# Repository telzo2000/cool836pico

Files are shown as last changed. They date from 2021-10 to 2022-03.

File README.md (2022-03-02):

# cool836pico

# build guide
https://github.com/telzo2000/cool836pico/blob/main/buildguide_cool836pico.md

# Note
cool836picoを完成したので、忘備録として記入します。
<br>
cool836picoは、m.kiが設計したキーボードです。<br>
cool836Aをベースにして、従来のpro microから、Raspberry pi pico（以下、ピコ）を採用し、配線処理等を新規設計したものである。<br>
特徴は、前述のピコを採用したこと。<br>
cool836Aと同じ、アリス配列をもしたキーレイアウトであること。<br>
スイッチソケットを採用して、Cherry MXとkailh chocの両方が使えること。<br>
これら３点が挙げられる。<br>
基板の設計は、kicadで行った。すでにピコのfootprintを作った人がいたので、それを使った。
キーレイアウトは、cool836Aと同じため、前に使ったレイアウトのjsonファイルを再利用した。
配線処理は、cool836Aが最初にSU120を使ったものであったときの名残りで、colとrowは６x６であった。
この点を改善しようと思い、１２x３に変更した。その分、配線処理は簡易となったと思う。<br>
ピコはpro microと違い、基板本体にリセットスイッチを持っている。そのため、基板への設置面に制約がある。
なるべく、チップ類が露出しない方が良いと考えて、PCBに切り込みを入れる形にした。
マックエイトのスプリングピンヘッダを使用する限り、あまり関係ない仕様かもしれない。
一般的なピンヘッダでハンダ付けをした場合、この仕様は生きてくると思う。<br>
ネジ穴の位置は、外装となるアクリルプレートを考慮して配置した。
ただし、二種類の高低差のあるスイッチが使用できるため、それに合わせたスイッチプレートの形状とした。
結果として、ピコのカバー部分のアクリルプレートを２種類用意することで解決した。<br>
これまでのcool836Aのような形状では難しくなり、菱形のような形状となった。
今後、ピコの設置の場所について、洗練できれば、形状の見直しも視野に入れようと思う。<br>
ファームウェアについては、python系のkmk_firmwarexとrubyのprk_firmwareの２種類がある。両方試してみた。
どちらにもいえることが、pro microで使うqmk_firmwareよりも多分、作りやすいと思う。
逆にどちらもコンパイルの場面がないので、エラー表示を見て一つ一つ直していくことができない。
原因を探るのが難しかった。<br>
最初に上手く行ったのは、prk_firmwareのほうだった。
しかし、この文章はkmk_firmwareを装備したcool836picoで入力している。<br>
~~今後、どちらが優位になるか、私にはわからない。~~<br>
（令和4年２月25日追記）<br>
最近、メンテナンスに時間を割くことができず、記述が古いままでした。
ちょっとだけ時間に余裕ができたので、追記します。
<br>
cool836picoは、よくわかりませんが、prk_firmwareでも、kmk_firmawareでも動作します。
<br>
cool836rpの初期版（boothで＜訳あり版＞として頒布）は、prkでファームが作れたのですが、なぜか、kmkで作れませんでした。
GP29を使用したのが、ダメだったのかと勝手に考えています。
<br>そのため、cool836rp＜正式版＞では、GP29を使わないで配線してあります。
<br>
私自身、何度も書きますが、非IT系の業界で、この辺りの知識量はとても少なく、先人たちの足跡を追いながら、日々精進している状態です。

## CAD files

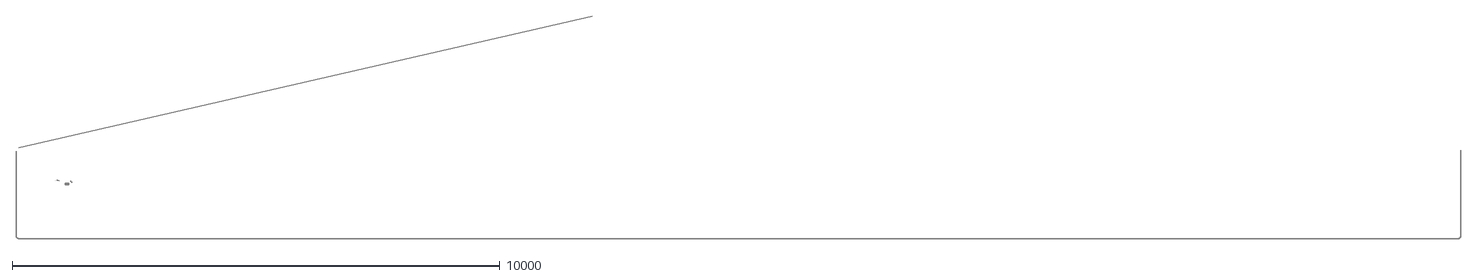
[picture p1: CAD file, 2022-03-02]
case/cool836picocasedesig.dxf
29627.7 x 4564.4

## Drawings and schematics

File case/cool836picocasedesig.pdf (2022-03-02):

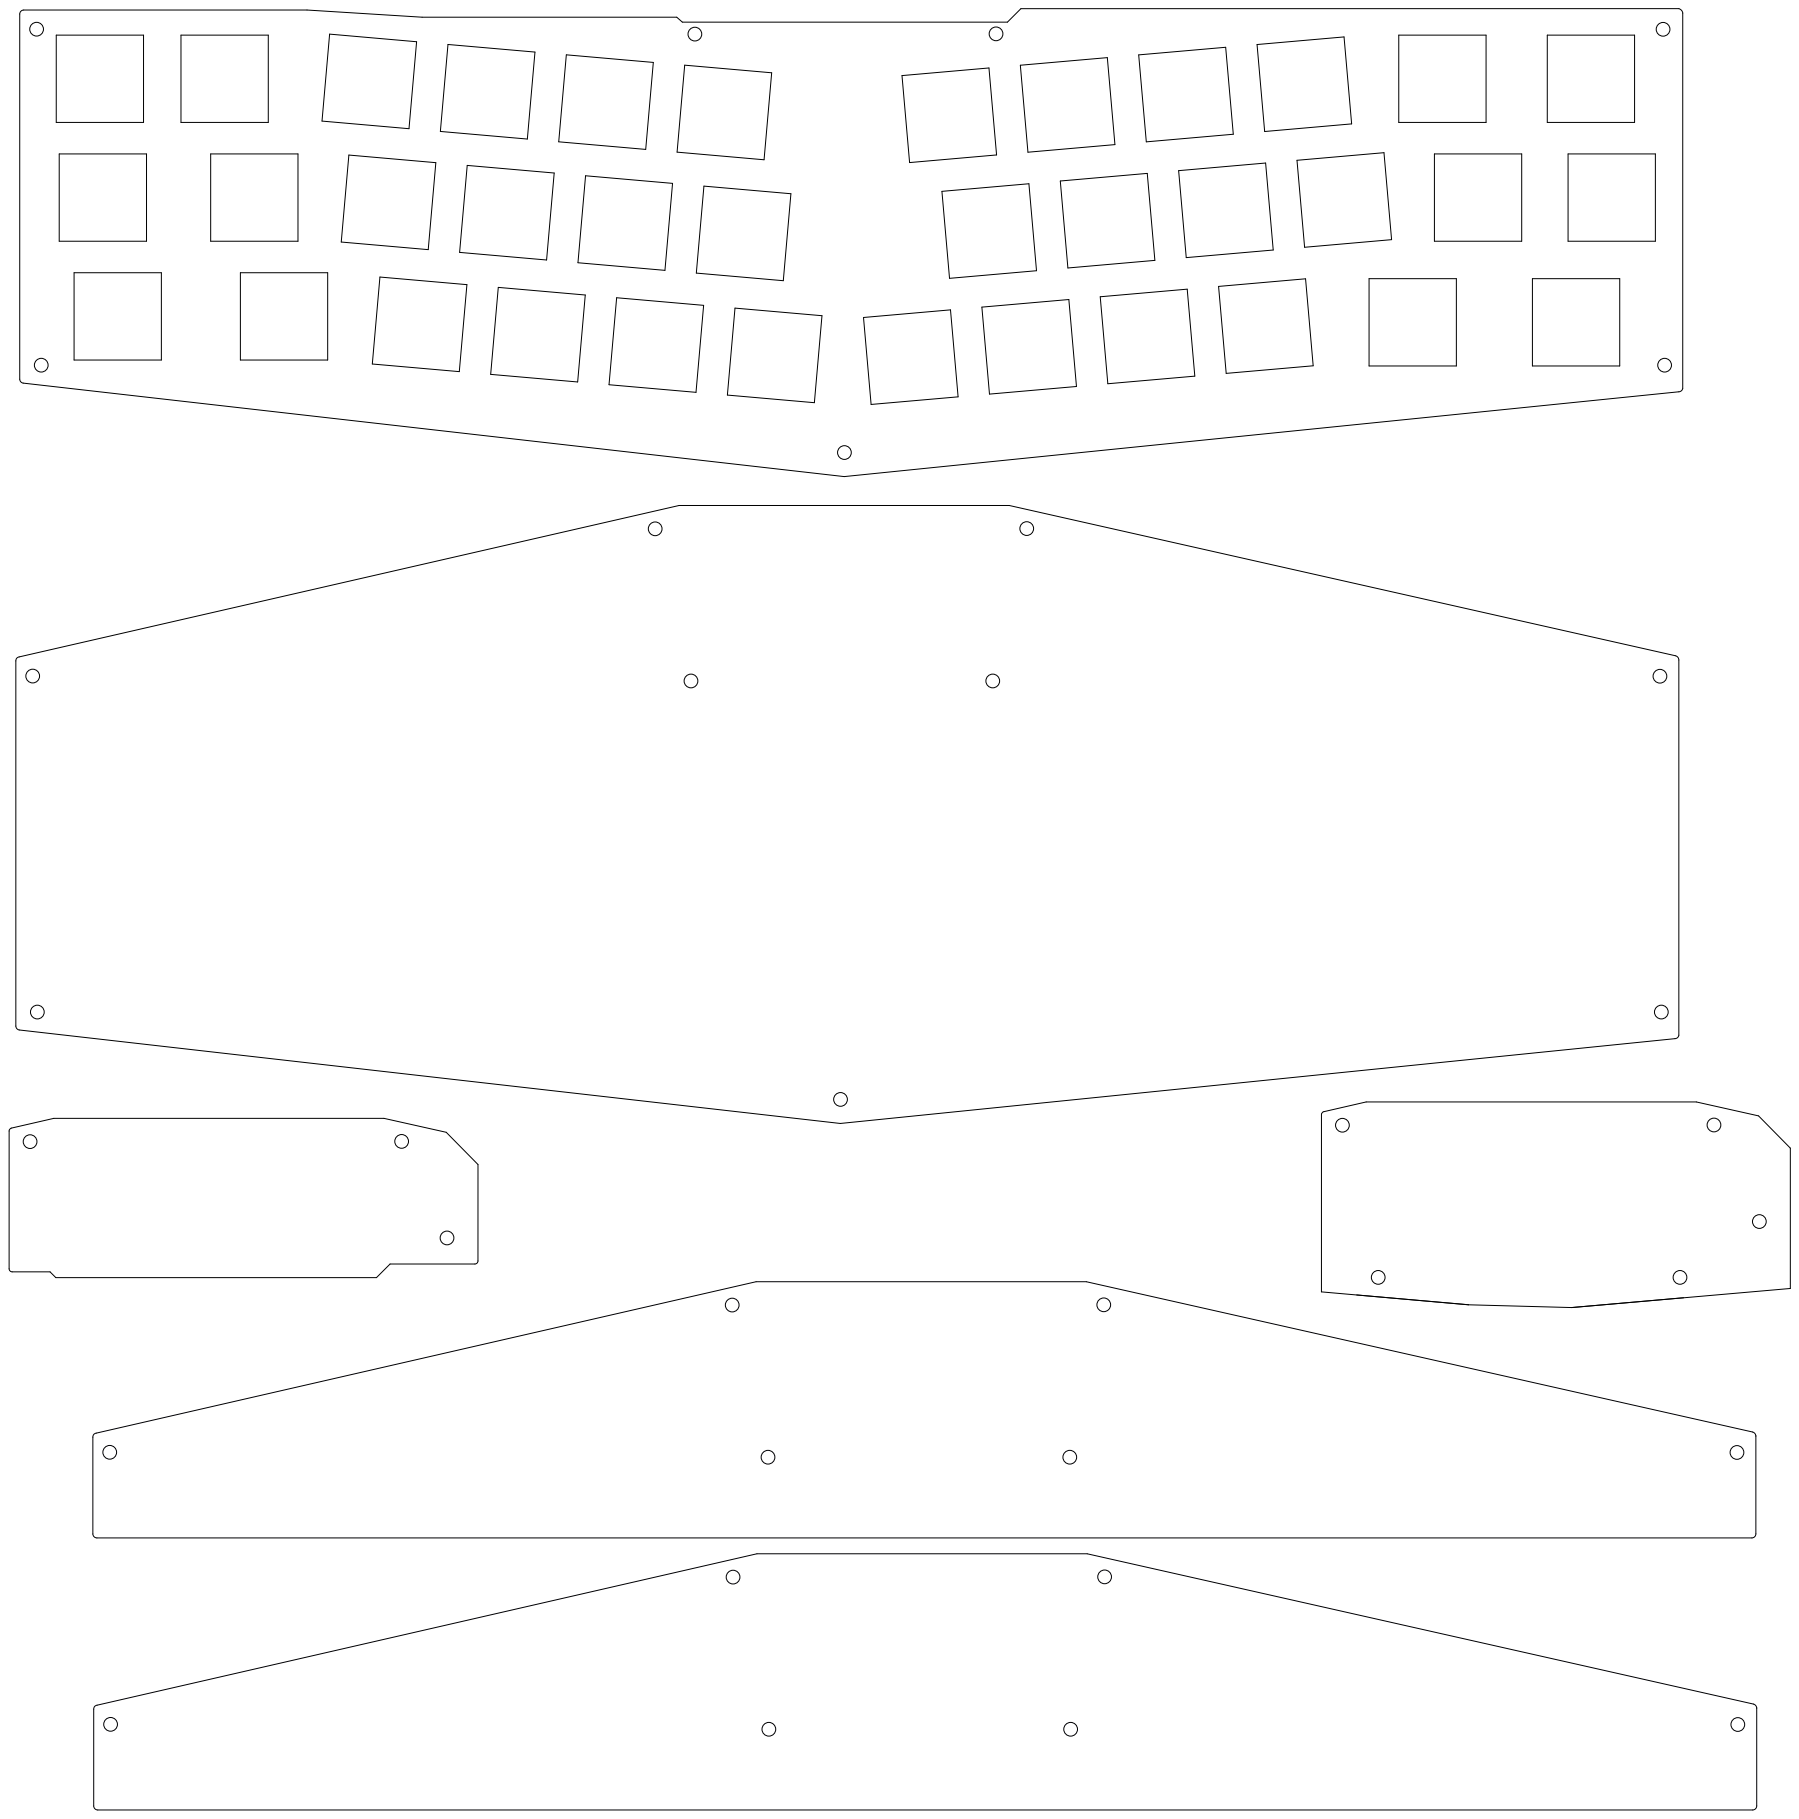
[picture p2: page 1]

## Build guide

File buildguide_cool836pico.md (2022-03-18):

# cool836pico　ビルドガイド

**写真**

cool836pico　chocスイッチ採用
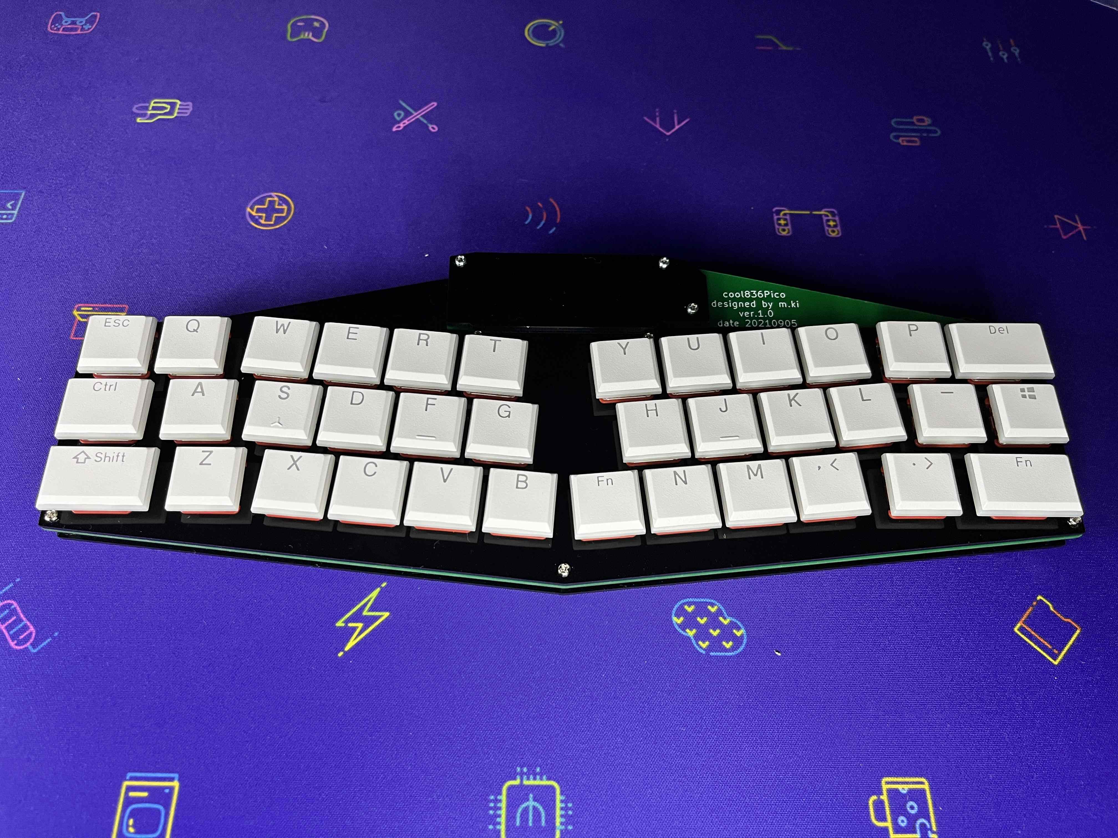
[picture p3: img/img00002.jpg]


<br>
<br>

**特徴**
<br>
・30％Alice  layout<br>
・サンドイッチマウント、チルト0〜10度<br>
・PCB、トッププレート、ボトムプレートそれぞれFR4を使用。<br>
・36キー（choc、MXソケットによるキースイッチ交換可能）<br>
<br>

## Parts List

修正中。
<br><br>

## ファームウェア
このキーボードはkmk_firmwareというキーボード用のソフトウェアで動作するようにプログラミングしています。<br>
私自身、非IT系ゆえに、先人の知恵（ネットで拾った情報）を借りながら、kmk_firmwareの部分を仕上げました。
そのため、購入者からの質問に答えるほどの知識、技術がありません。
ご容赦ください。
<br>
~~また、ruby（prk_firmware）でも、動作しましたが、私の知識、技術では、一部の挙動を制御しきれず、ちょっと公開するまでのファームウェアにならなかったため、掲載しません。~~
動作実績はありますので、お試しください。
<br>
準備出来次第、追記します。prk_firmwareで必要なkeymap.rbは、[ここ](https://github.com/telzo2000/cool836pico/tree/main/firmware_fo_prk)にあります。

<br>
<br>

**1 CircuitPythonの導入**
<br>
KMKを導入する前に，以下の手順でraspberry pi pico（以下、Pico）にCircuitPythonの実行環境を書き込む必要があります。

**ステップ１**
<br>
CircuitPythonの公式サイトからPico用のCircuitPythonのファームウェアをダウンロードします。
https://circuitpython.org/board/raspberry_pi_pico/

**ステップ２**
<br>
PicoのBOOTSELボタンを押しながらUSBケーブルを接続し，Picoに対応するドライブにステップ1でダウンロードした.uf2ファイルをドラッグ＆ドロップします。

<br>

**２　KMK本体のコピー**
<br>
KMKのCircuitPythonスクリプトはGitHub 上で公開されており，これらのCircuitPythonスクリプトをPicoに書き込むことによってKMKを使用できる状態になります。
<br>

**ステップ1**
<br>
以下のKMKのGitHubリポジトリからKMKの本体をダウンロードします．
https://github.com/KMKfw/kmk_firmware/archive/7a30cc8ccea4111d9b953033599f176579b8091b.zip

**ステップ2**
<br>
ダウンロードしたZipファイルを展開し，中にあるkmkディレクトリをPicoのlibディレクトリの下に丸ごとコピーします。

**３　code.pyの配置**
<br>
Picoのルート・ディレクトリにcode.pyをコピーします。<br>

[cool836pico用のcode.py](https://github.com/telzo2000/cool836pico/tree/main/firmware_for_kmk)
<br>
書き込みが完了すると自動的にリセットがかかります。
<br>

**４キー配列のカスタマイズ**
<br>
code.pyのkeymap設定部分を書き換えることにより，自分の好きなキー配列に設定できます。
<br>
詳細は、KMKのドキュメントをお読みください。code.pyを書き換えると、キーマップの変更ができます。
<br>
**（令和３年11月3日追記）**
<br>
私個人の感想だが、kmk_firmwareそのままだと、キー長押しの時間がややもっさりしていると感じる。
kmk_keyboard.pをエディタで開いて、tap_time=200とした。
前よりは長押しが反応するまでの時間がややもっさりしていると感じたが、少し改善された気がする。
<br>

## 組み立て手順
<br>

### １　基板の確認

組み立ての前に、PCB、トッププレート、ボトムプレート１式の上・下面を確認します。PCB表面の右上に「cool836Pico」と印刷されています。印刷されている面が、上面となります。
他のプレートはねじ穴位置を合わせて、上面を確認してください。
上・下面が違うと、ネジが正しく入りません。<br>
<br>

### ２　ダイオードのハンダ付け
ダイオードは、足のついているもの（リードタイプ）と足のついていないもの（SMD）の２種類が使えます。
<br>
**chocスイッチ**を使用する場合、SMDタイプのダイオードをお勧めします。
リードタイプですと、トッププレートとPCBの間にハンダが残り、トッププレートが浮いてしまいます。
<br>
**MXスイッチ**を使用する場合は、どちらのダイオードでも大丈夫です。
ダイオードはPCBの裏面に本体が残るように、ハンダ付けしてください。
ハンダ付けに自信がない場合、フラックスを利用すると、上手にハンダ付けができます。
その後、フラックスクリーナーで綺麗に拭き取ることをお勧めします。
<br>

### ３ スイッチソケットのハンダ付け
cool836picoは、chocソケットおよびMXソケットに対応しています。
どちらかを選んでつけても良いですし、両方をつけることもできます。
<br>
ソケットのハンダ付けでは、ソケットの向きに注意してください
ソケットの端子がPCBと接する箇所片方に、予備ハンダをしておくと、ハンダ付けが上手くいきます。
上手くハンダ付けができない場合、フラックスを多めに塗布して行うと、ハンダがソケットの端子とPCBの端子の間に流れていきます。
その後、フラックスクリーナーで綺麗に拭き取ることをお勧めします。

<br>
ダイオード、chocソケット、MXソケットがハンダ付けされたPCB

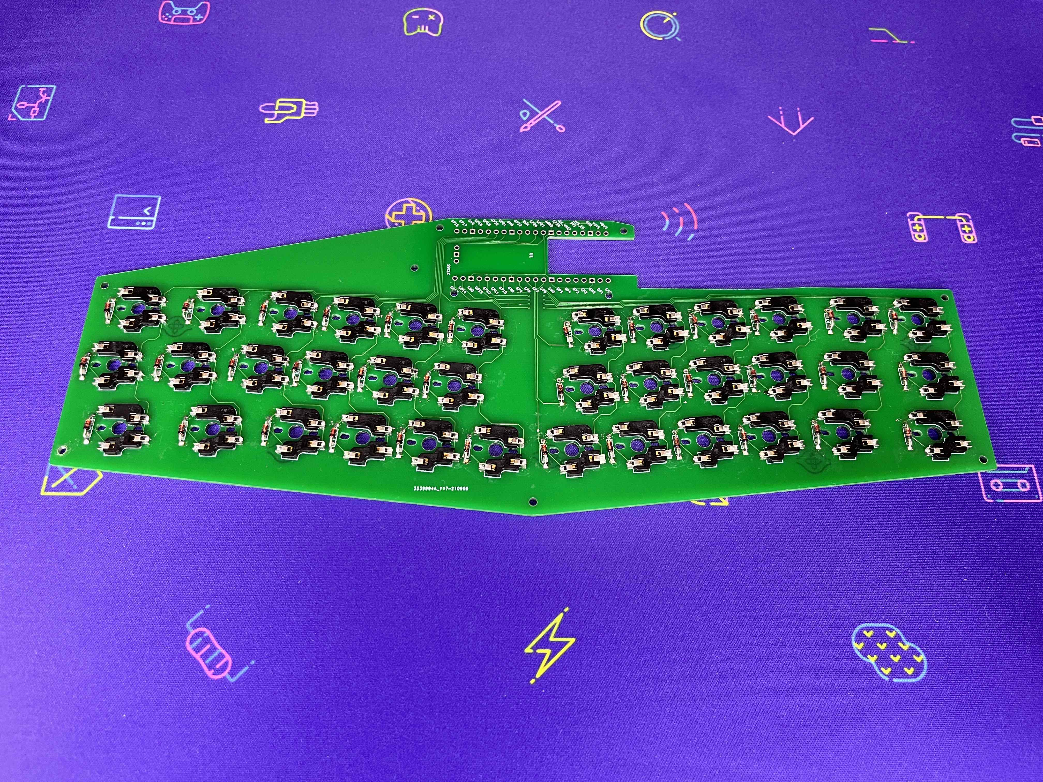
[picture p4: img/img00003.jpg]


<br>

### ４　Picoの取り付け
このビルドガイドではコンスルー（スプリングピンヘッダ）を使用して
Picoの装着をしました。
Picoの装着箇所が、PCB下側であるため、時間が経つと、落下する可能性があります。
ボトムプレートがあるので、紛失することはありません。
ハンダ付けによる固定を推奨します。
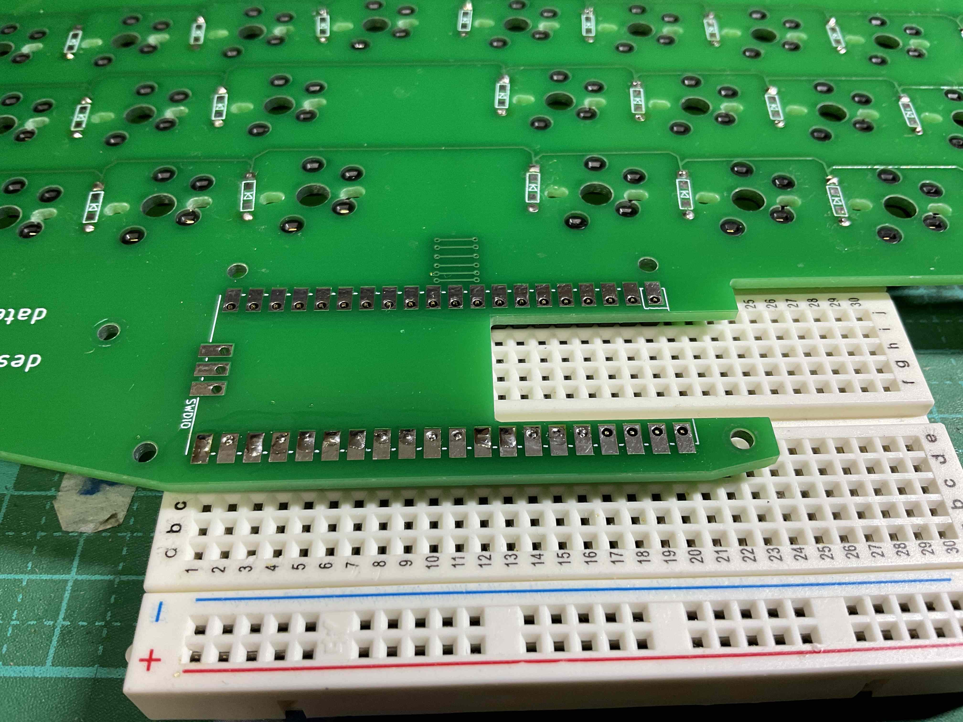
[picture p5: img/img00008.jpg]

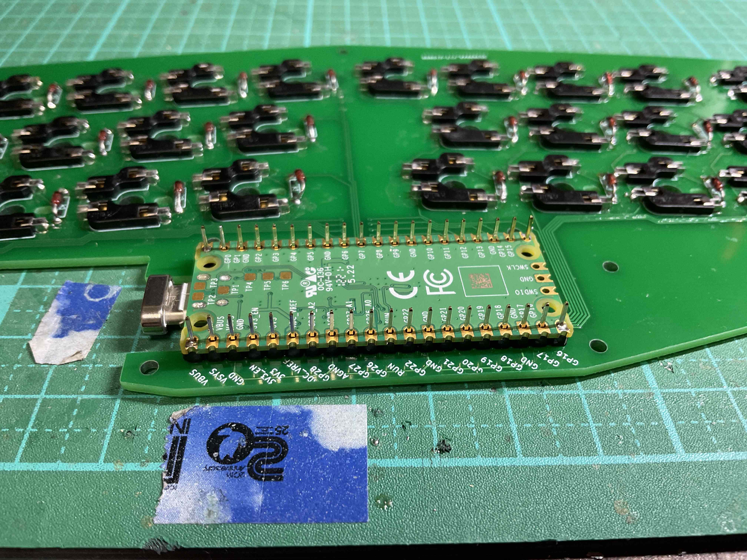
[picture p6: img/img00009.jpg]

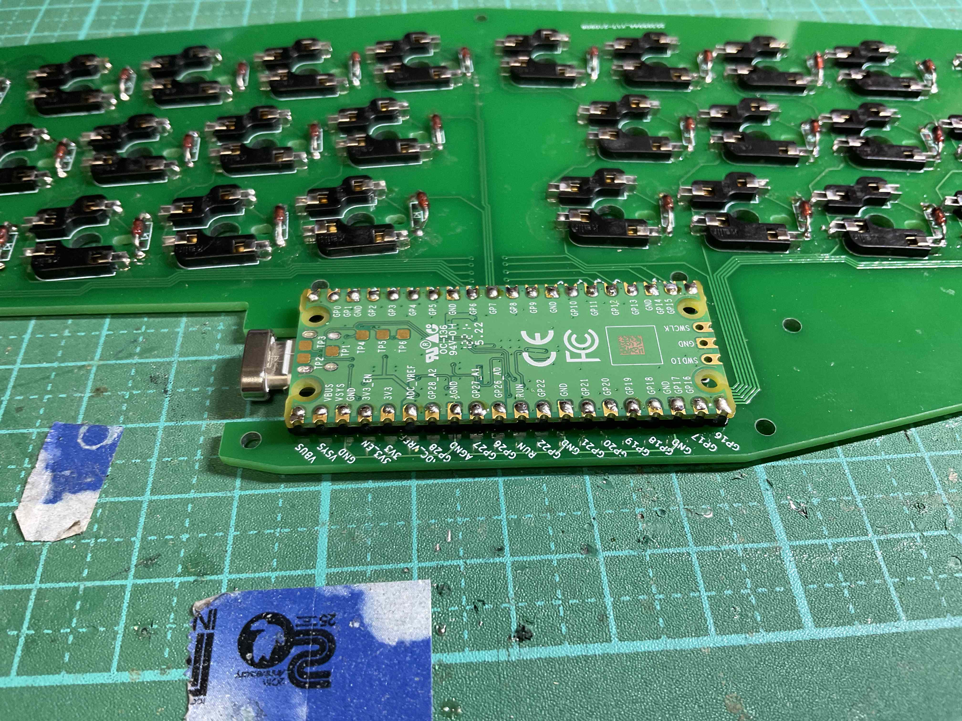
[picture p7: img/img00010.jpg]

<br>
コンスルー（スプリングピンヘッダ）を使用するときは、向きに気をつけて使用してください。
<br>

### ５　カバープレートの取り付け
カバープレートのそれそれのネジ穴にM2ネジ8mmを通して、反対側でナットで締めます。そのあと、カバープレートをPCB表面に載せます。<br>
PCBの向きを変えて、裏面からM2スペーサー6mmを２つ、M2ナットを１つで、固定します。
<br>
上面から
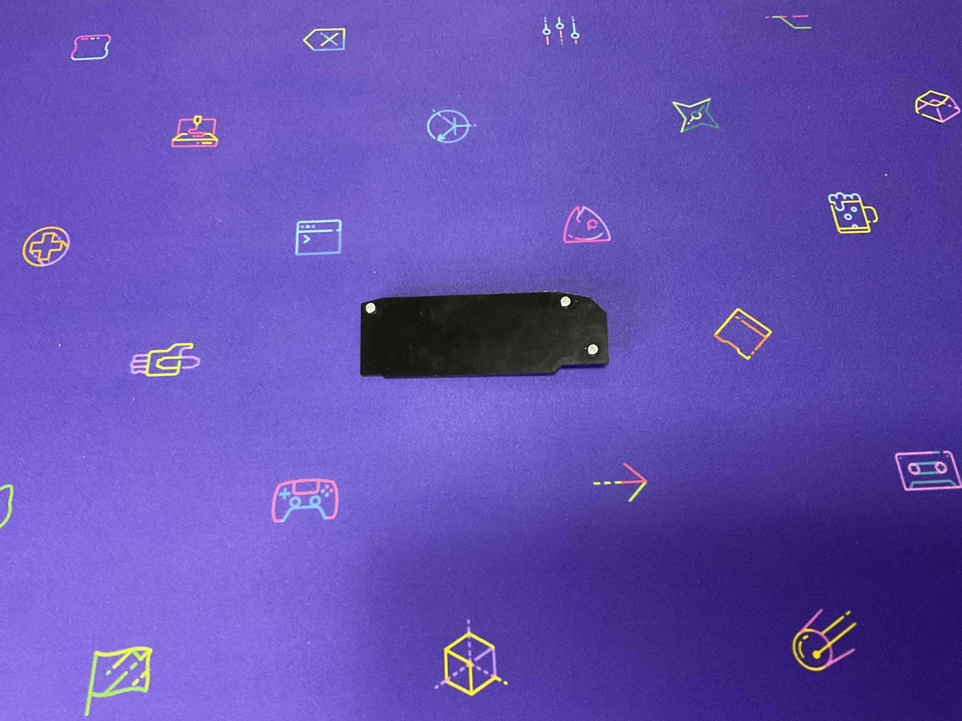
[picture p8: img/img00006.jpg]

下面から
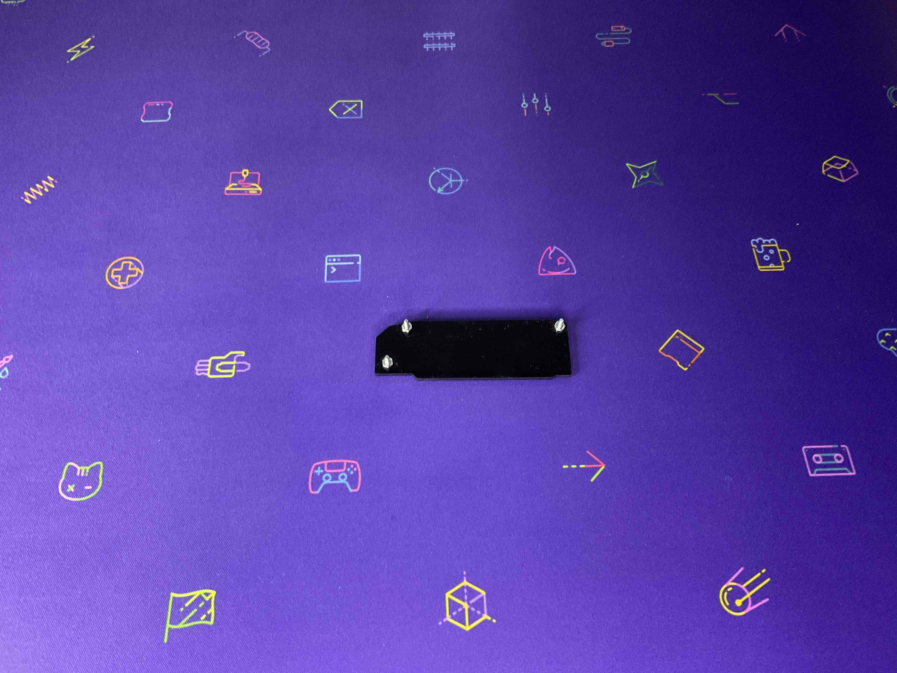
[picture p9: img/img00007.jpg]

PCBに載せた上面の様子
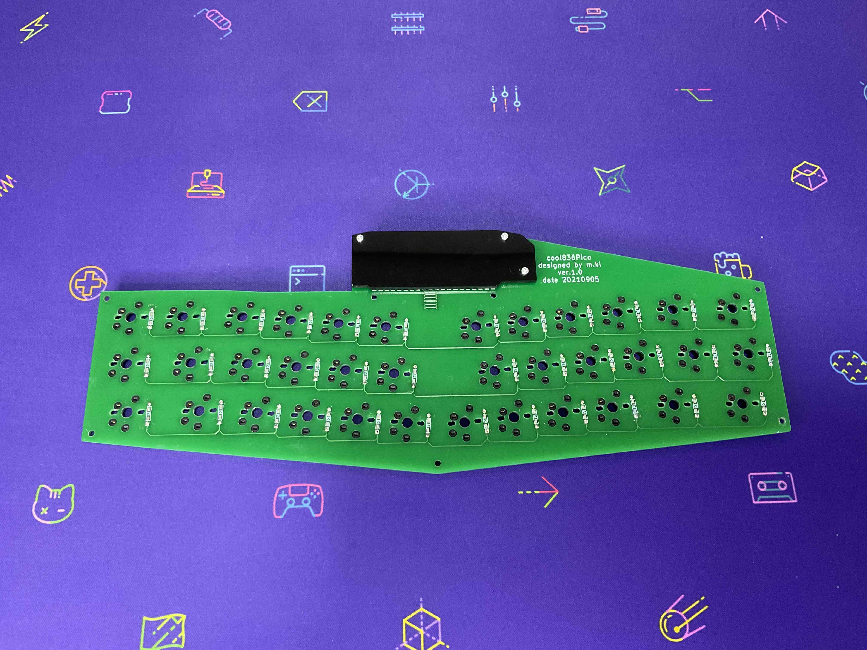
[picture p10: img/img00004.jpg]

PCBに載せた下面の様子
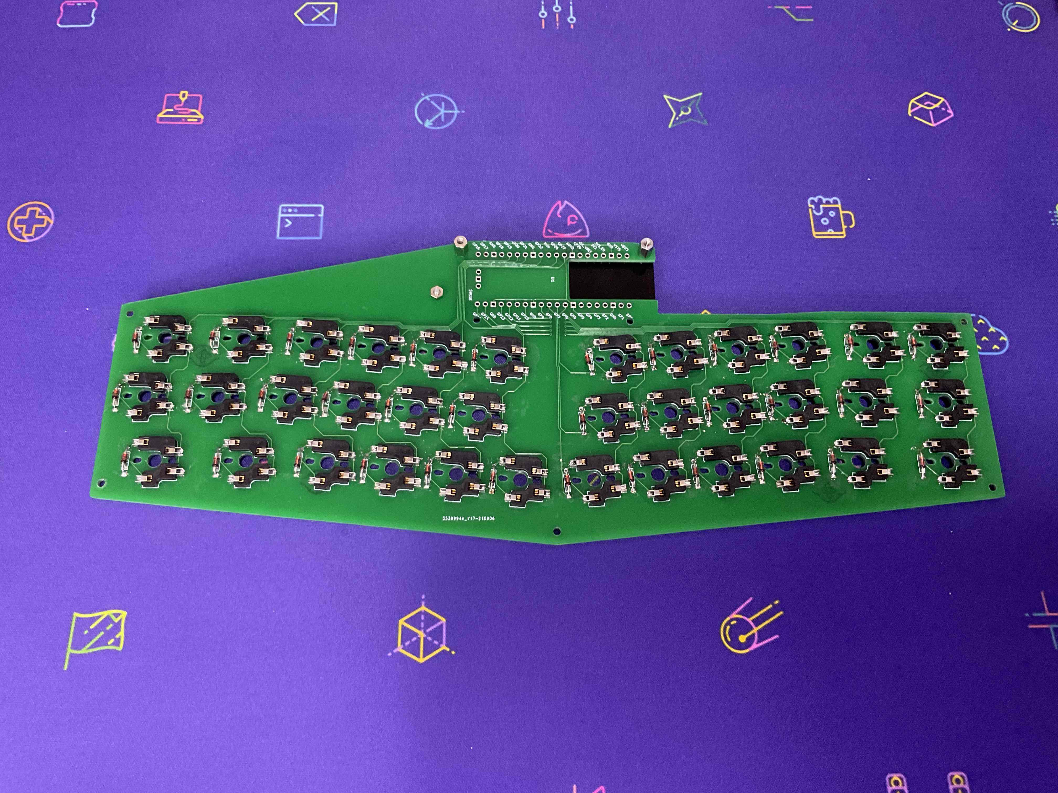
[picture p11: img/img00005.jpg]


<br>
　<br>

### ６a　スイッチプレート、ソケットの取り付け　choc編<br>
スイッチプレートの上下の向きに注意して、PCB上面に載せて、７箇所にネジ（M2 6mm）を上面から挿しこみ、PCB下面からスペーサー（M2 6mm）で固定します。
<br>
その後、chocスイッチを挿していきます。スイッチの足が曲がらないように注意してください。

<br>

### ６b スイッチプレート、ソケットの取り付け　cherryMX編
最初にスイッチプレートのの上下の向きに注意して、上面から７箇所にネジ（M2 8mm）を挿しこみ、下面からスペーサー（M2 3mm）でゆるく固定します。
<br>
次にキースイッチ５個をスイッチプレートの５箇所（四隅と一番手前）に差し込みます。
一度に全部のキースイッチを取り付けて、その後にPCBにハンダ付けしたMXソケットに差し込むとうまくいかないことが予想されます。
５箇所で一度PCBにハンダ付けしたMXソケットに差し込み、残りのキースイッチをトッププレート、PCBの順に差し込んでください。それぞれのキースイッチの足がきちんとMXソケットの基板の穴に差し込まれていることを確認してください。
差し込むときに、足が曲がってしまうことがあります。
その場合は、ボタンを押しても入力されません。
一度キースイッチを外して、足の修正または新しいキースイッチに交換等対処してください。<br>
その次に、PCB下面からスペーサー（M2 6mm）で固定します。その後、残りのMXソケットを取り付けてください。
<br>

### ７　ボトムプレートの取り付け<br>
ボトムプレート1式は次の３つパーツで構成されています。<br>
- ボトムプレート大　１枚
- ボトムプレート小　２枚

PCB裏面を上向きにします。そこに、形が揃うように、ボトムプレート大を載せて、３箇所をネジ（M2 4mm）で固定します。
<br>

PCB裏面が上向きの様子
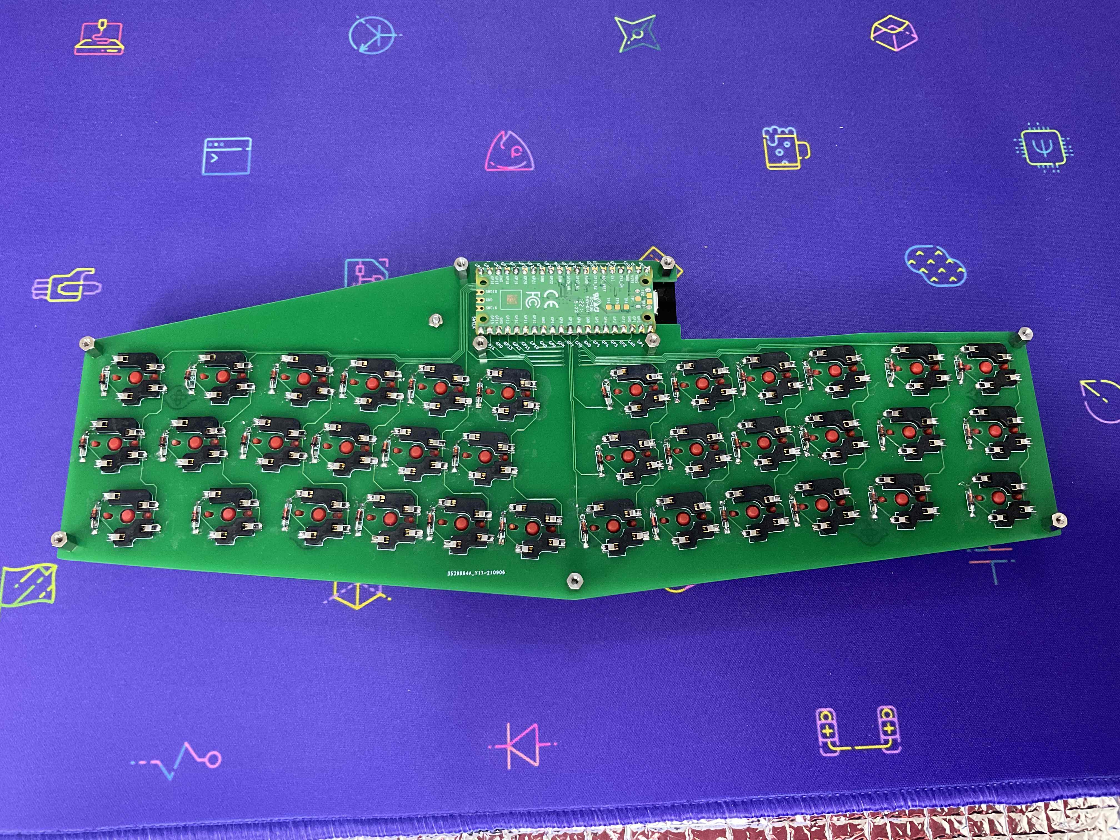
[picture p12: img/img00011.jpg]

ボトムプレート大を載せてネジで固定
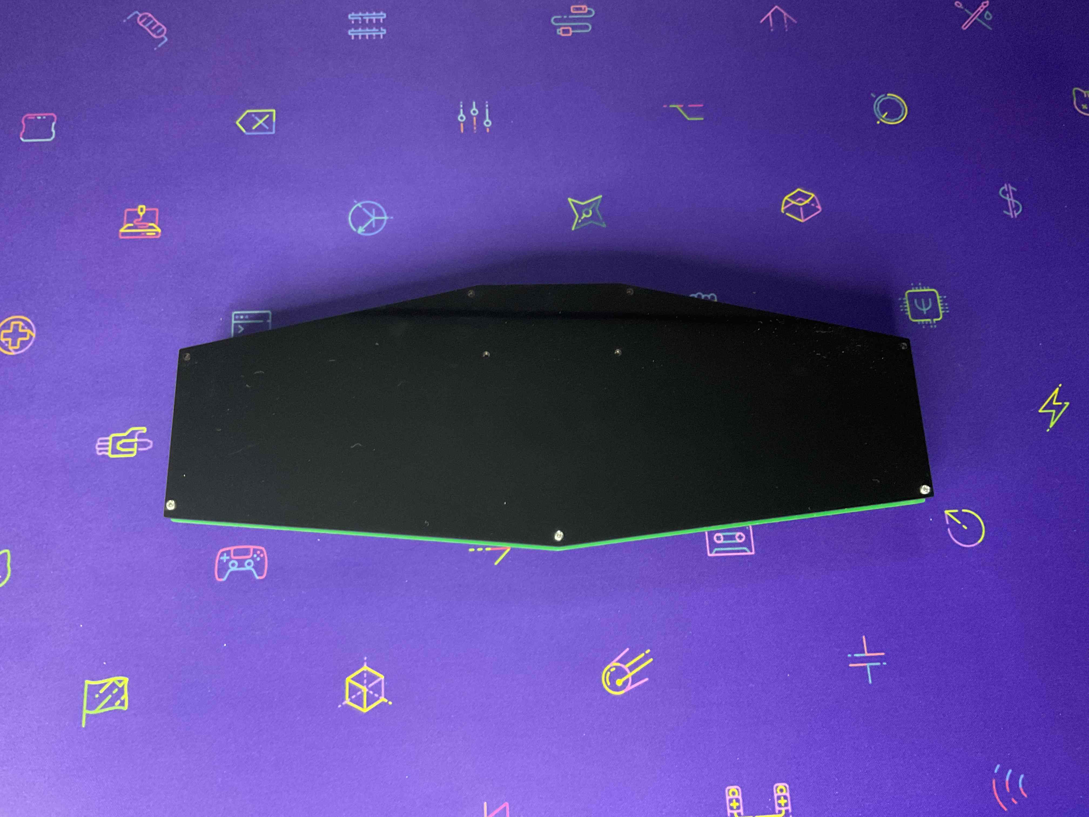
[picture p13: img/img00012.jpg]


<br>
次にボトムプレート小を１・２枚（任意）載せて、６箇所をネジ（M2 8mm）で固定します。

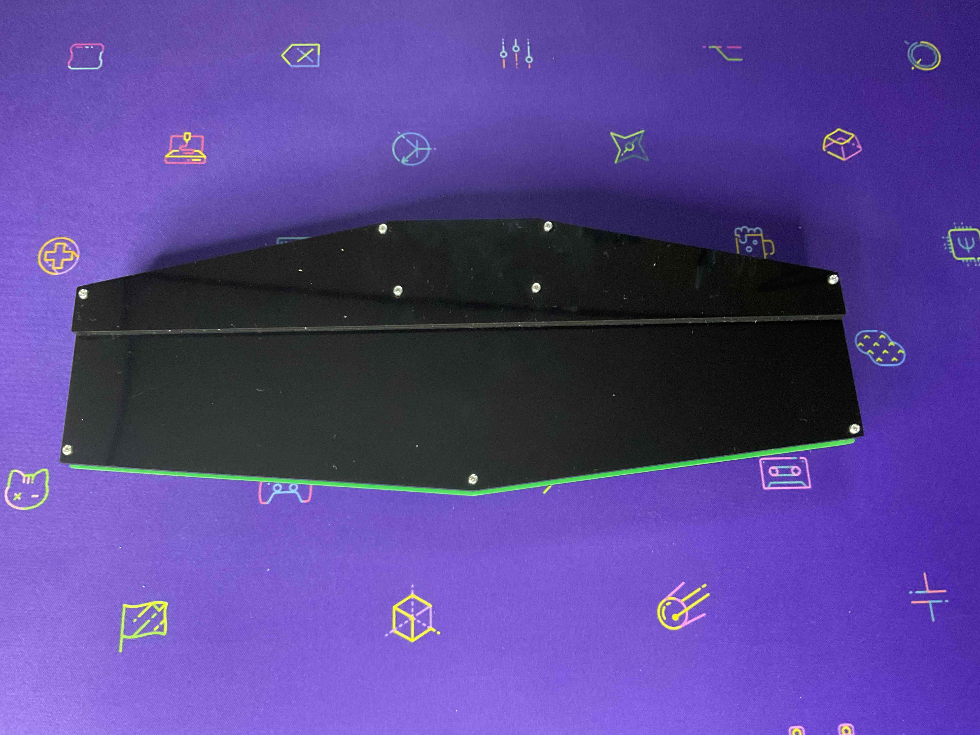
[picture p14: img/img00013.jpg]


また、ボトムプレート小を使わないと、傾斜のないフラットなキーボードになります。試してみて、最適な角度で使用してください。

<br>
その後、お好みでクッションゴムを取り付けてください。<br>
<br>
組み立ての手順は、以上です。<br>
<br>

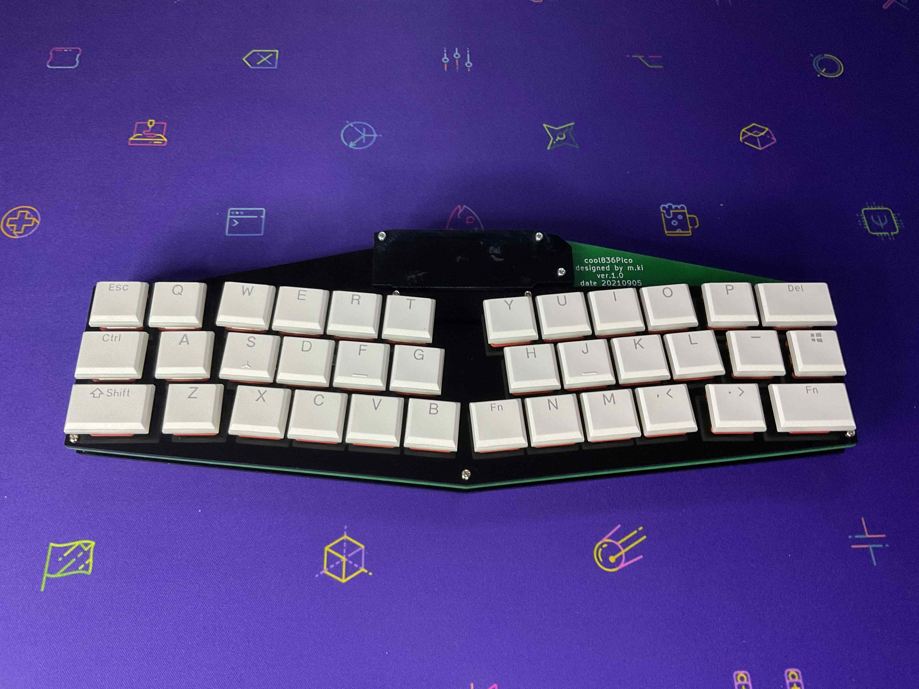
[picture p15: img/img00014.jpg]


気に入っていただけたら、幸いです。　<br>

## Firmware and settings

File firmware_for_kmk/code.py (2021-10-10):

import board

from kmk.kmk_keyboard import KMKKeyboard
from kmk.keys import KC
from kmk.matrix import DiodeOrientation
from kmk.modules.layers import Layers
from kmk.modules.modtap import ModTap



keyboard = KMKKeyboard()

keyboard.row_pins = (board.GP6,board.GP7,board.GP8,)
keyboard.col_pins = (board.GP9,board.GP10,board.GP12, board.GP13, board.GP14, board.GP15, board.GP27, board.GP26, board.GP22, board.GP21, board.GP20, board.GP19,)
keyboard.diode_orientation = DiodeOrientation.COL2ROW
keyboard.modules.append(Layers())
keyboard.modules.append(ModTap())

keyboard.keymap = [
    [#0
        KC.ESC,     KC.MT(KC.Q, KC.LALT),   KC.W,  KC.E,  KC.R, KC.T, KC.Y,     KC.U, KC.I, KC.O,    KC.P,     KC.BSPC,
        KC.LCTRL,   KC.A,   KC.S,  KC.D,  KC.F, KC.G, KC.H,     KC.J, KC.K, KC.L,    KC.MINS,  KC.ENT,
        KC.LSFT,    KC.MT(KC.Z,KC.LGUI),   KC.MT(KC.X, KC.LGUI),  KC.C,  KC.V, KC.LT(2,KC.B), KC.SPACE, KC.LT(1,KC.N), KC.M, KC.COMM, KC.DOT,   KC.SPACE,
    ],
    [#1
        KC.TAB,     KC.N1,     KC.N2,   KC.N3,    KC.N4,     KC.N5,      KC.N6,         KC.N7,        KC.N8,    KC.N9,         KC.N0,          KC.BSPC,
        KC.LCTRL,   KC.EXLM,   KC.AT,   KC.HASH,  KC.DOLLAR, KC.PERCENT, KC.CIRCUMFLEX, KC.AMPERSAND, KC.ASTERISK, KC.LEFT_PAREN, KC.RIGHT_PAREN, KC.ENT,
        KC.LSFT,    KC.PLUS,   KC.MINS, KC.PAST,  KC.SLASH,  KC.EQUAL,   KC.NO,      KC.N,         KC.M,       KC.LSFT(KC.LBRC),       KC.LSFT(KC.RBRC),         KC.SPACE,
    ],
    [#2
        KC.TAB,     KC.F1,     KC.F2,   KC.F3,    KC.F4,     KC.F5,      KC.F6,         KC.F7,        KC.F8,    KC.F9,         KC.F10,          KC.BSPC,
        KC.LCTRL,   KC.AT,   KC.BSLASH,   KC.SCOLON,  KC.LSFT(KC.SCOLON), KC.QUOTE, KC.LEFT, KC.DOWN, KC.UP, KC.RIGHT, KC.LSFT(KC.SLASH), KC.ENT,
        KC.LSFT,    KC.PLUS,   KC.MINS, KC.PAST,  KC.SLASH,  KC.EQUAL,   KC.NO,      KC.GRAVE,         KC.M,       KC.LBRC,       KC.RBRC,         KC.SPACE,
    ],
]

if __name__ == '__main__':
    keyboard.go()
